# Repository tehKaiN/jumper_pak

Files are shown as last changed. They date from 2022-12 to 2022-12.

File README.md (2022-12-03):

# Jumper Pak

<div style="display: flex; flex-direction: row; justify-content: center;">
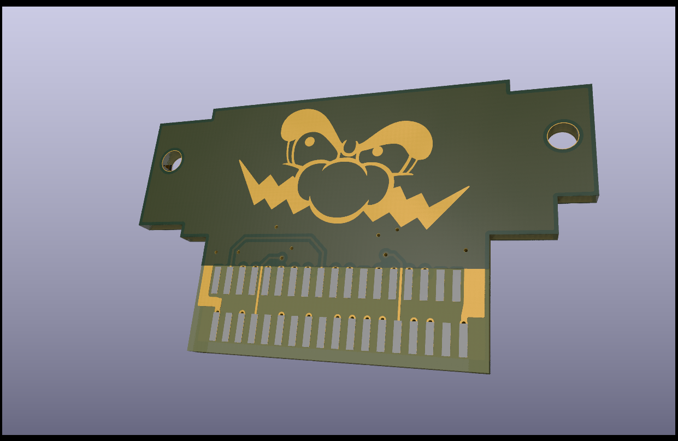
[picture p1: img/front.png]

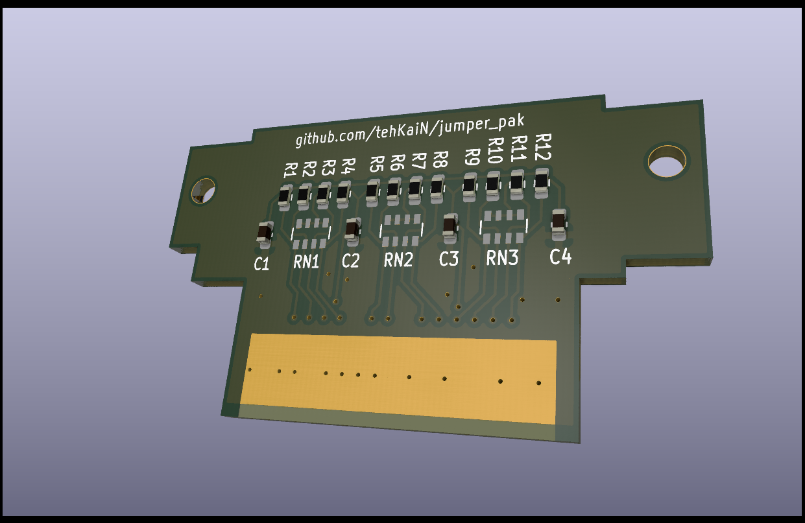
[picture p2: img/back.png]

</div>

This is an open-source Nintendo 64 Jumper Pak replacement.
Dimensions are captured from the original with caliper, with slight modifications.
Design is based on high resolution scans of the original and scraps of information found across the Internet.

I was commissioned to do this, and I don't have the actual hardware, but the project was tested by other people and proven to work.
The PCB contains the footprints for both resistor packs as well as single 0603 resistors.
**Don't solder both of them! Choose one type!**

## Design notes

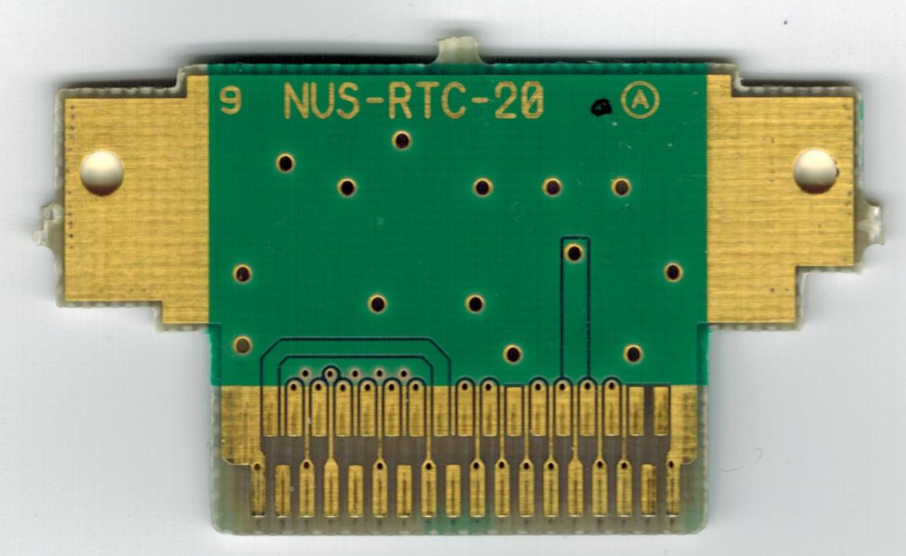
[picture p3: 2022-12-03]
res/jumper_pak_scan_600dpi.png

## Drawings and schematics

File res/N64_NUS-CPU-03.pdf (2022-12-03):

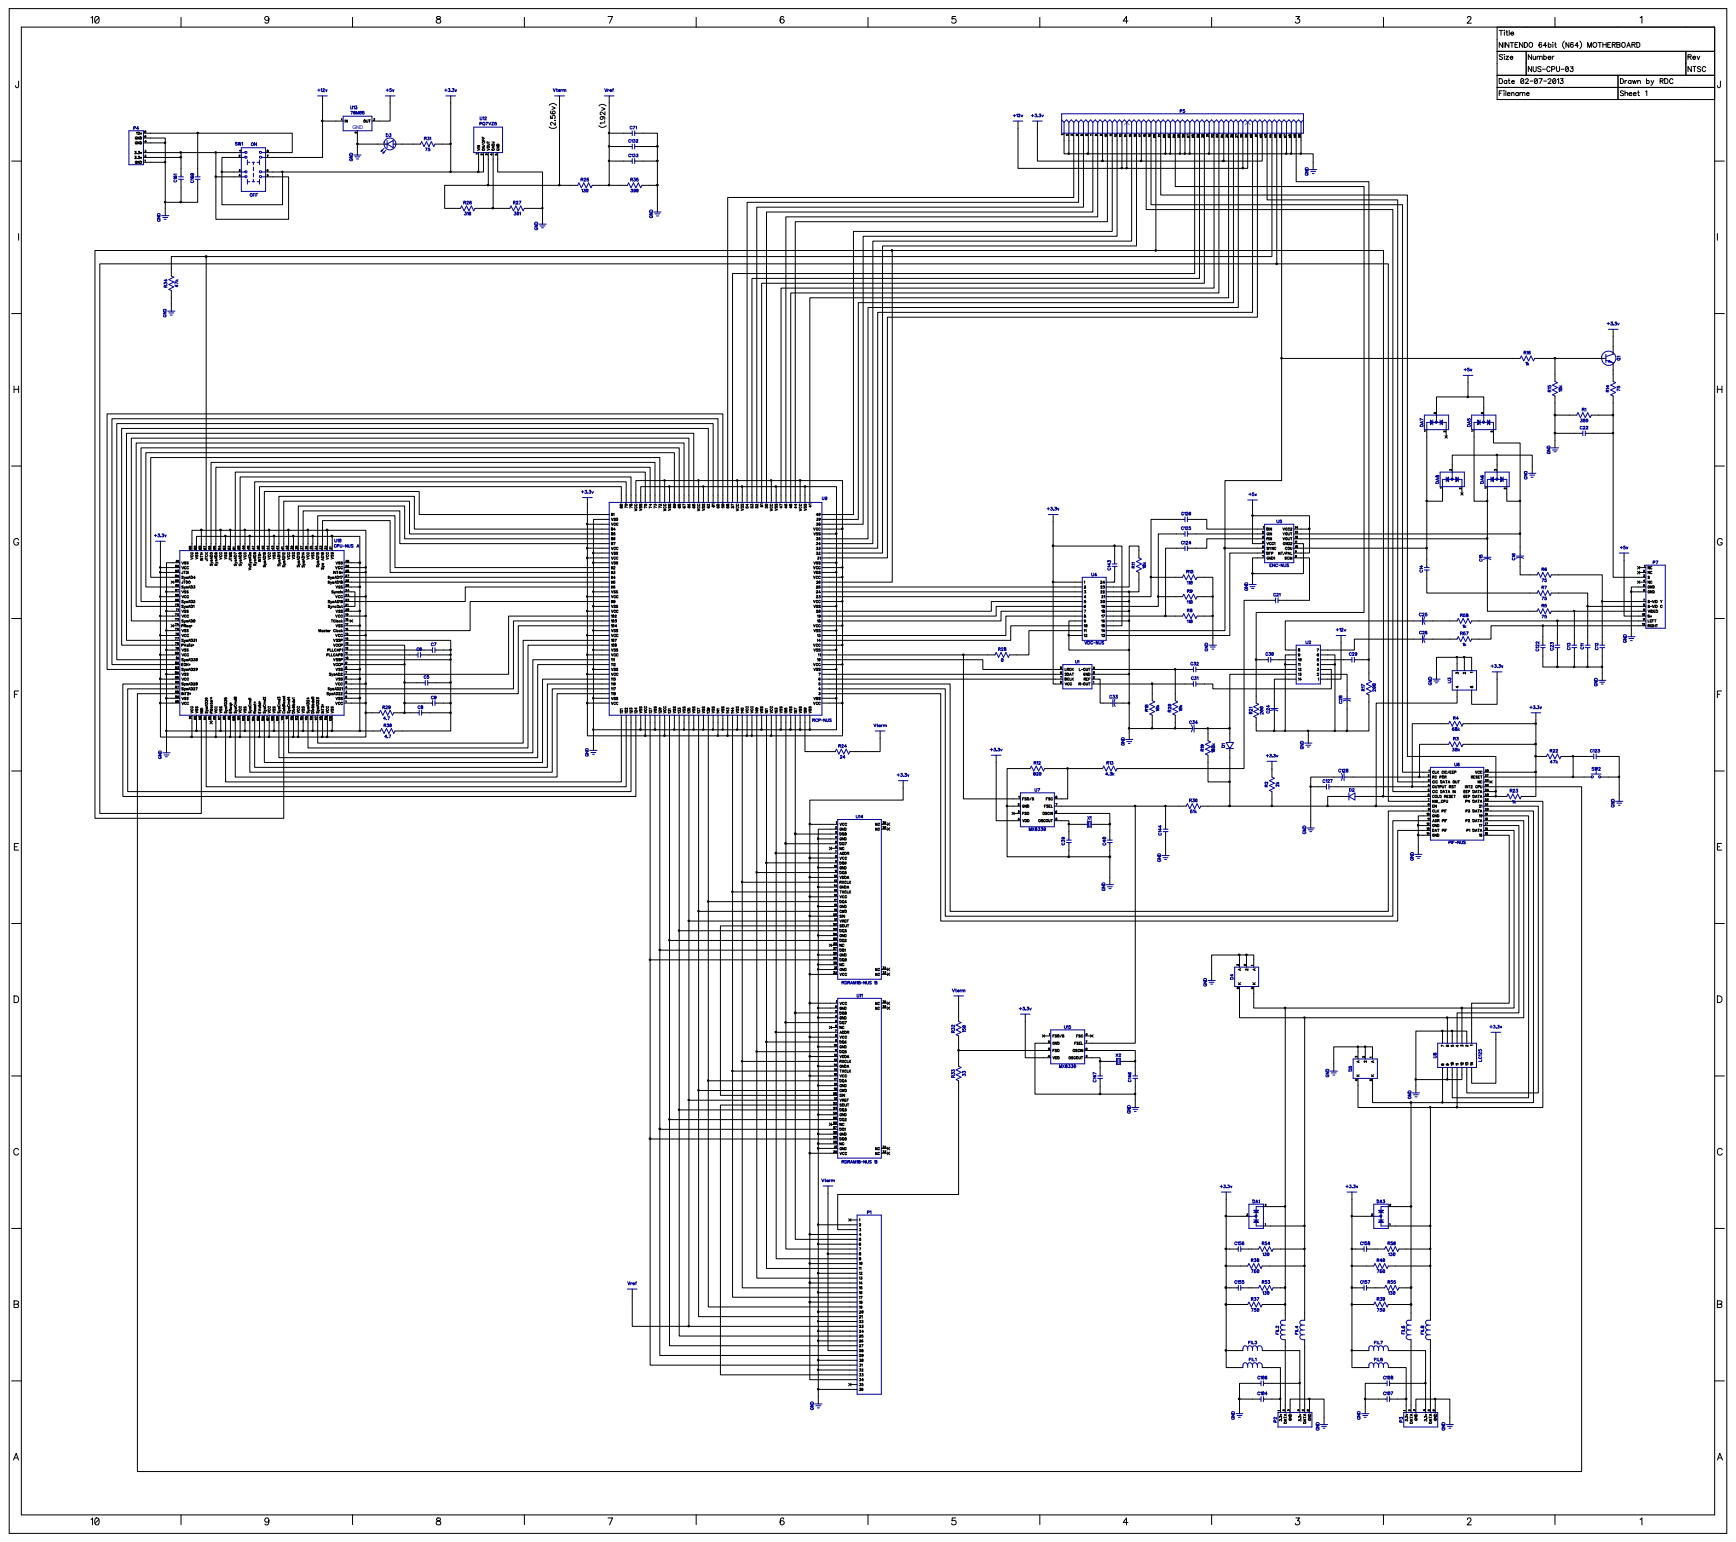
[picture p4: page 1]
GND

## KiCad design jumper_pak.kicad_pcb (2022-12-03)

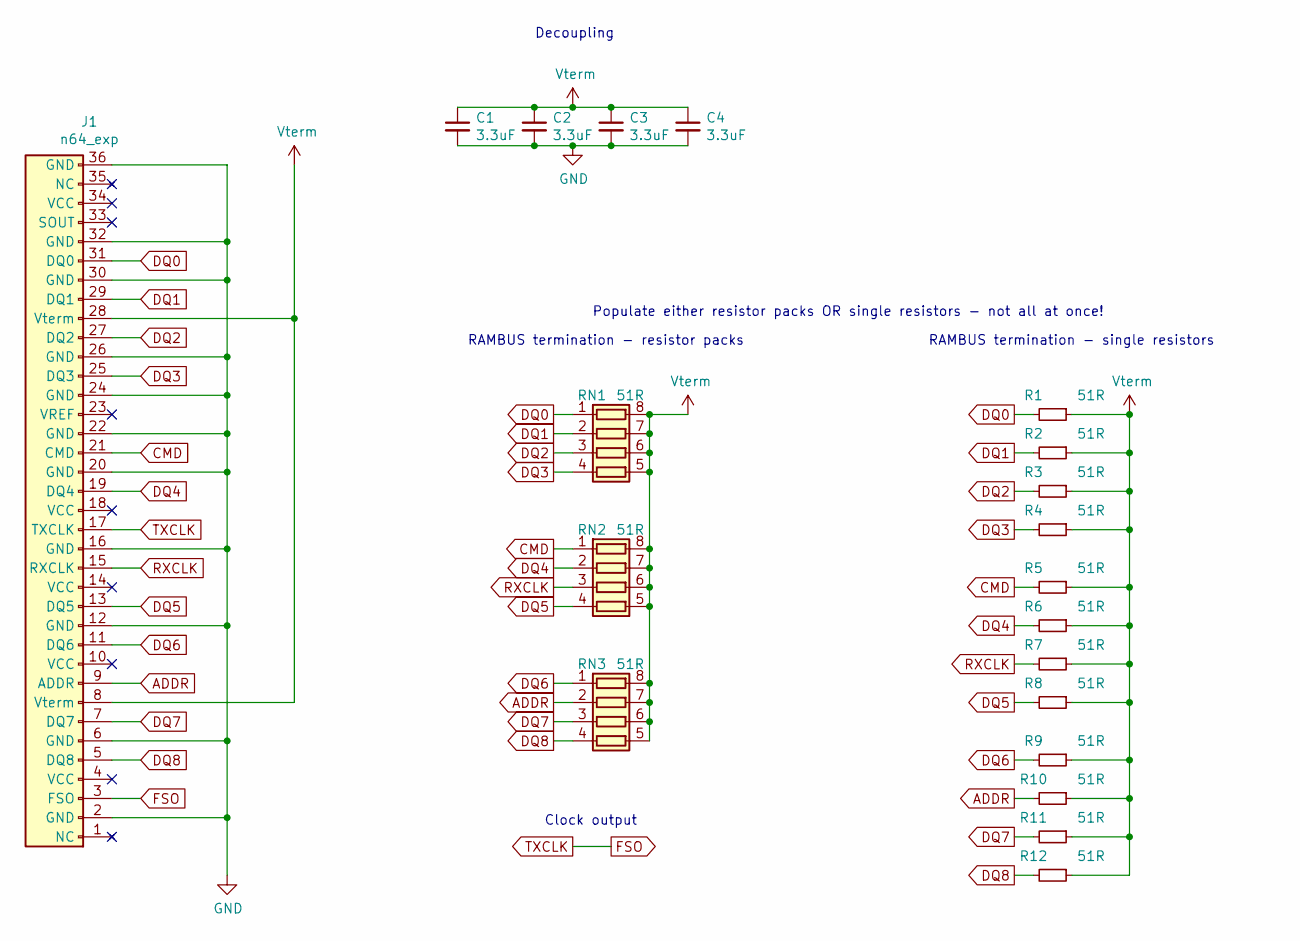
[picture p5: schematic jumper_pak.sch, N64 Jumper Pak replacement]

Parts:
C1, C2, C3, C4: 3.3uF; C_0603_1608Metric
J1: n64_exp; ram-pak-edge-conn
R1, R2, R3, R4, R5, R6, R7, R8, R9, R10, R11, R12: 51R; R_0603_1608Metric
RN1, RN2, RN3: 51R; R_Array_Convex_4x0603

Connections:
ADDR: J1.9 (ADDR), R10.2, RN3.2 (R2.1)
CMD: J1.21 (CMD), R5.2, RN2.1 (R1.1)
DQ0: J1.31 (DQ0), R1.2, RN1.1 (R1.1)
DQ1: J1.29 (DQ1), R2.2, RN1.2 (R2.1)
DQ2: J1.27 (DQ2), R3.2, RN1.3 (R3.1)
DQ3: J1.25 (DQ3), R4.2, RN1.4 (R4.1)
DQ4: J1.19 (DQ4), R6.2, RN2.2 (R2.1)
DQ5: J1.13 (DQ5), R8.2, RN2.4 (R4.1)
DQ6: J1.11 (DQ6), R9.2, RN3.1 (R1.1)
DQ7: J1.7 (DQ7), R11.2, RN3.3 (R3.1)
DQ8: J1.5 (DQ8), R12.2, RN3.4 (R4.1)
FSO: J1.3 (FSO), J1.17 (TXCLK)
GND: C1.2, C2.2, C3.2, C4.2, J1.2 (GND), J1.6 (GND), J1.12 (GND), J1.16 (GND), J1.20 (GND), J1.22 (GND), J1.24 (GND), J1.26 (GND), J1.30 (GND), J1.32 (GND), J1.36 (GND)
RXCLK: J1.15 (RXCLK), R7.2, RN2.3 (R3.1)
VCC: C1.1, C2.1, C3.1, C4.1, J1.8 (Vterm), J1.28 (Vterm), R1.1, R2.1, R3.1, R4.1, R5.1, R6.1, R7.1, R8.1, R9.1, R10.1, R11.1, R12.1, RN1.5 (R4.2), RN1.6 (R3.2), RN1.7 (R2.2), RN1.8 (R1.2), RN2.5 (R4.2), RN2.6 (R3.2), RN2.7 (R2.2), RN2.8 (R1.2), RN3.5 (R4.2), RN3.6 (R3.2), RN3.7 (R2.2), RN3.8 (R1.2)

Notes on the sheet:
Decoupling
RAMBUS termination - resistor packs
Clock output
RAMBUS termination - single resistors
Populate either resistor packs OR single resistors - not all at once!

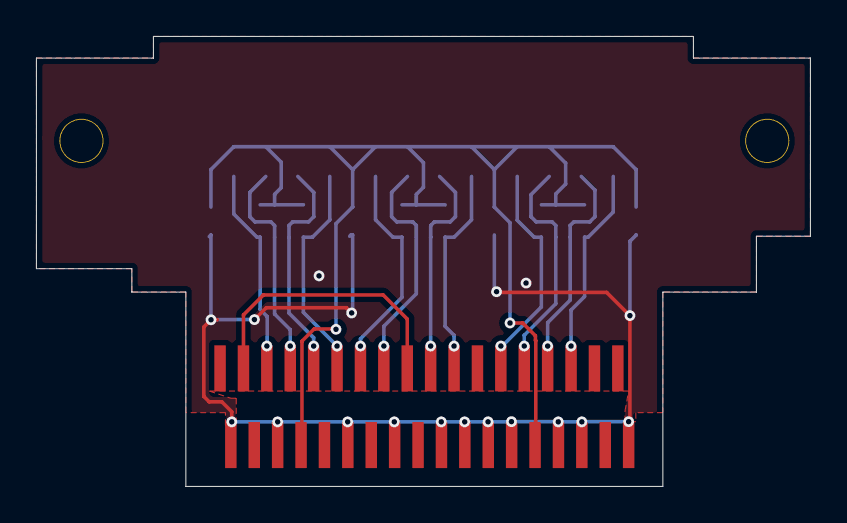
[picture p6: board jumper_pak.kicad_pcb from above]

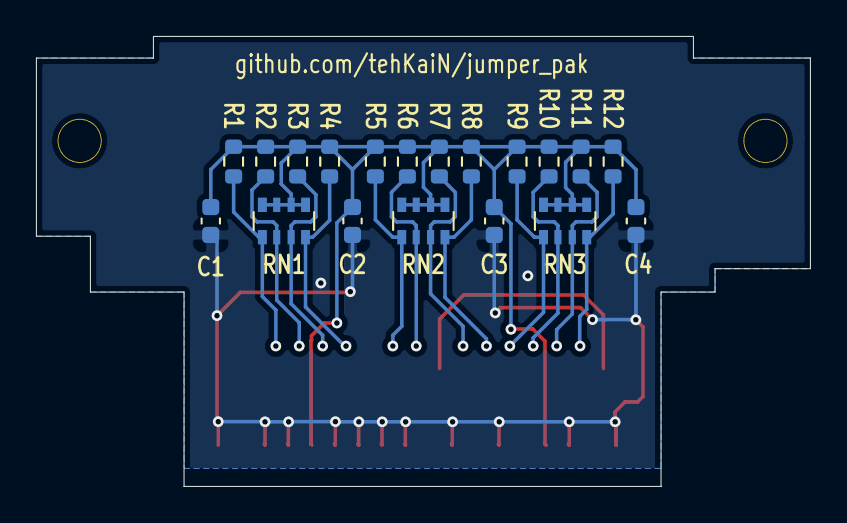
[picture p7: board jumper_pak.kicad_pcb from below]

Board: 2 copper layers, 43.0 x 25.0 mm, 20 parts (19 on the bottom side), 15 nets.

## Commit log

2022-12-03 added README.md
    [jumper_pak.kicad_pcb]
2022-12-03 added license
    [jumper_pak.kicad_pcb]
